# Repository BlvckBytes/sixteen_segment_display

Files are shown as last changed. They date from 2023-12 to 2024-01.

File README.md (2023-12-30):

# sixteen_segment_display

## PCB

### display_group

Four sixteen segment displays are considered to be a group.

### interface

The interface board drives a display group by converting the serial signal into all sixteen segments, including the decimal point, as well as each display's enabled state.

### driver

Has yet to be implemented.

The driver board resembles the bridge between modern devices and the display while also handling the process of detecting the total number of displays, handling the character decoding process, multiplexing displays and playing various animations, like blinking letters or scrolling text.

## Software

### SegmentStates

This project encodes all available segment states in order to display various characters. A decoding table is then generated from this information.

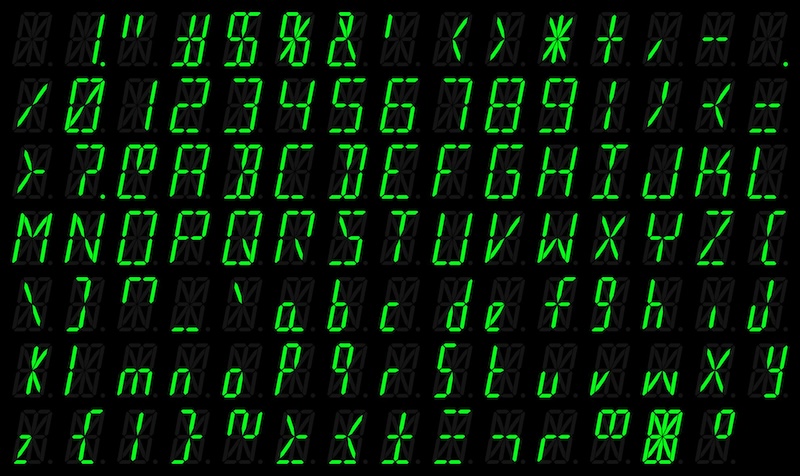
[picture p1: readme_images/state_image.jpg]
states


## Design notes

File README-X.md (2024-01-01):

<!-- This file is rendered by https://github.com/BlvckBytes/readme_helper -->

# sixteen_segment_display

<!-- #toc -->

## Overview

The following drawing represents the dimensions of the displays I've ordered a long time ago on aliexpress.

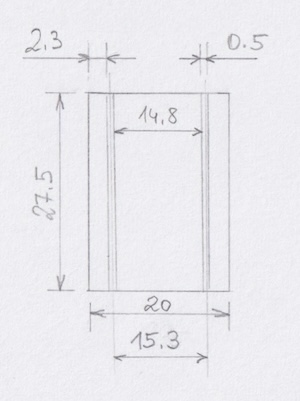
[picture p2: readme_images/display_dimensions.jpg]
Display Dimensions


The following high level diagram provides a quick overview of how groups of four displays each are talked to.

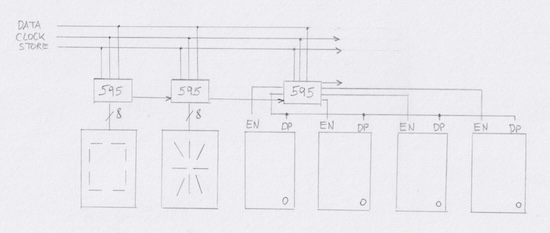
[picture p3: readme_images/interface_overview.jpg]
Interface Overview


## PCB

### display_group

Four sixteen segment displays are considered to be a group.

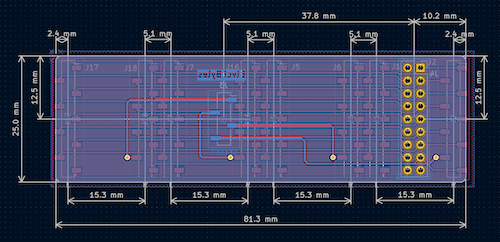
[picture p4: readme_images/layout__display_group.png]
Display Group Layout


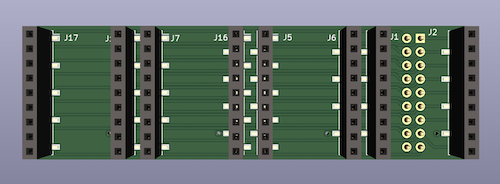
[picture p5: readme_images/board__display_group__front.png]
Display Group Front


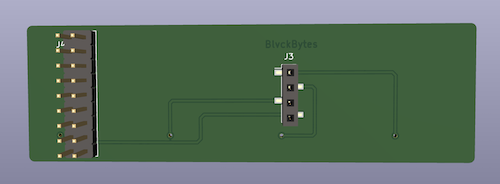
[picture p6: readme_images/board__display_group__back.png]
Display Group Back


### interface

The interface board drives a display group by converting the serial signal into all sixteen segments, including the decimal point, as well as each display's enabled state.

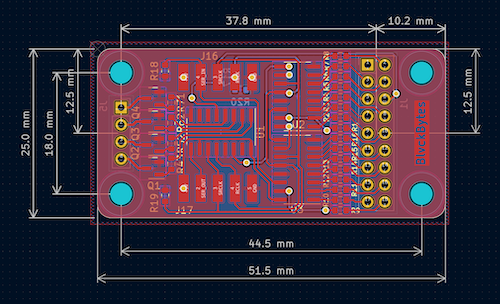
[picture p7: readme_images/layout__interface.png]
Interface Layout


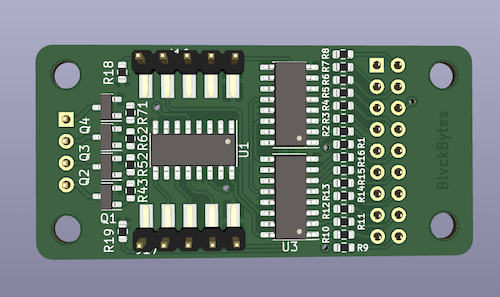
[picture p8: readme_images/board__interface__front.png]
Interface Front


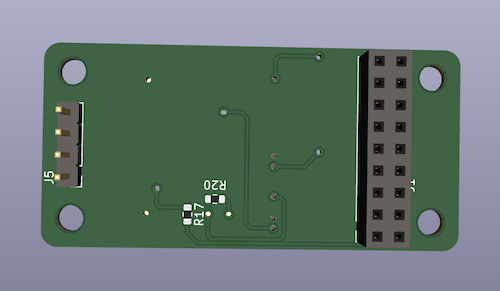
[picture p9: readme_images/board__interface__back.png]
Interface Back


### display_group_and_interface

This board tries to combine both the [Interface](#interface)- as well as the [Display Group Board](#display_group) to save not only on space, but also on the four extra connectors. While it's getting quite crowded, this board should still be manufacturable at home.

There are 35 vias in total, of which 21 are unavoidable (16 segments, 1 decimal point, 4 ground lines, which all have to make it from the front side to the back, where the interface lives), making for 14 "additional" vias. I think that's an acceptable compromise.

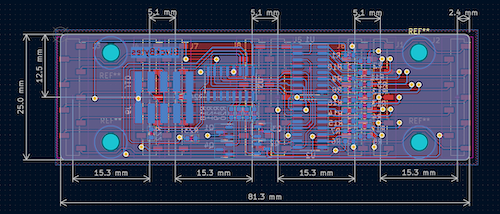
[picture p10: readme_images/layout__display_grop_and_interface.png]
Display Group And Interface Layout


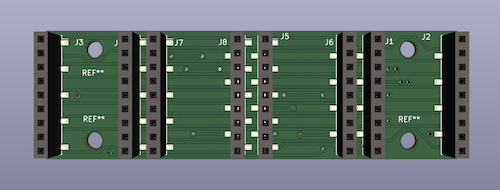
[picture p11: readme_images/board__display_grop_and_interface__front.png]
Display Group And Interface Front


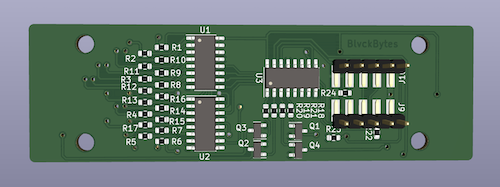
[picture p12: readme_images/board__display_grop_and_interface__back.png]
Display Group And Interface Back


### driver

Has yet to be implemented.

The driver board resembles the bridge between modern devices and the display while also handling the process of detecting the total number of displays, handling the character decoding process, multiplexing displays and playing various animations, like blinking letters or scrolling text.

## Software

### SegmentStates

This project encodes all available segment states in order to display various characters. A decoding table is then generated from this information.

states

### SegmentDriver

Has yet to be implemented.

This project resembles the firmware of the [Driver Board](#driver).

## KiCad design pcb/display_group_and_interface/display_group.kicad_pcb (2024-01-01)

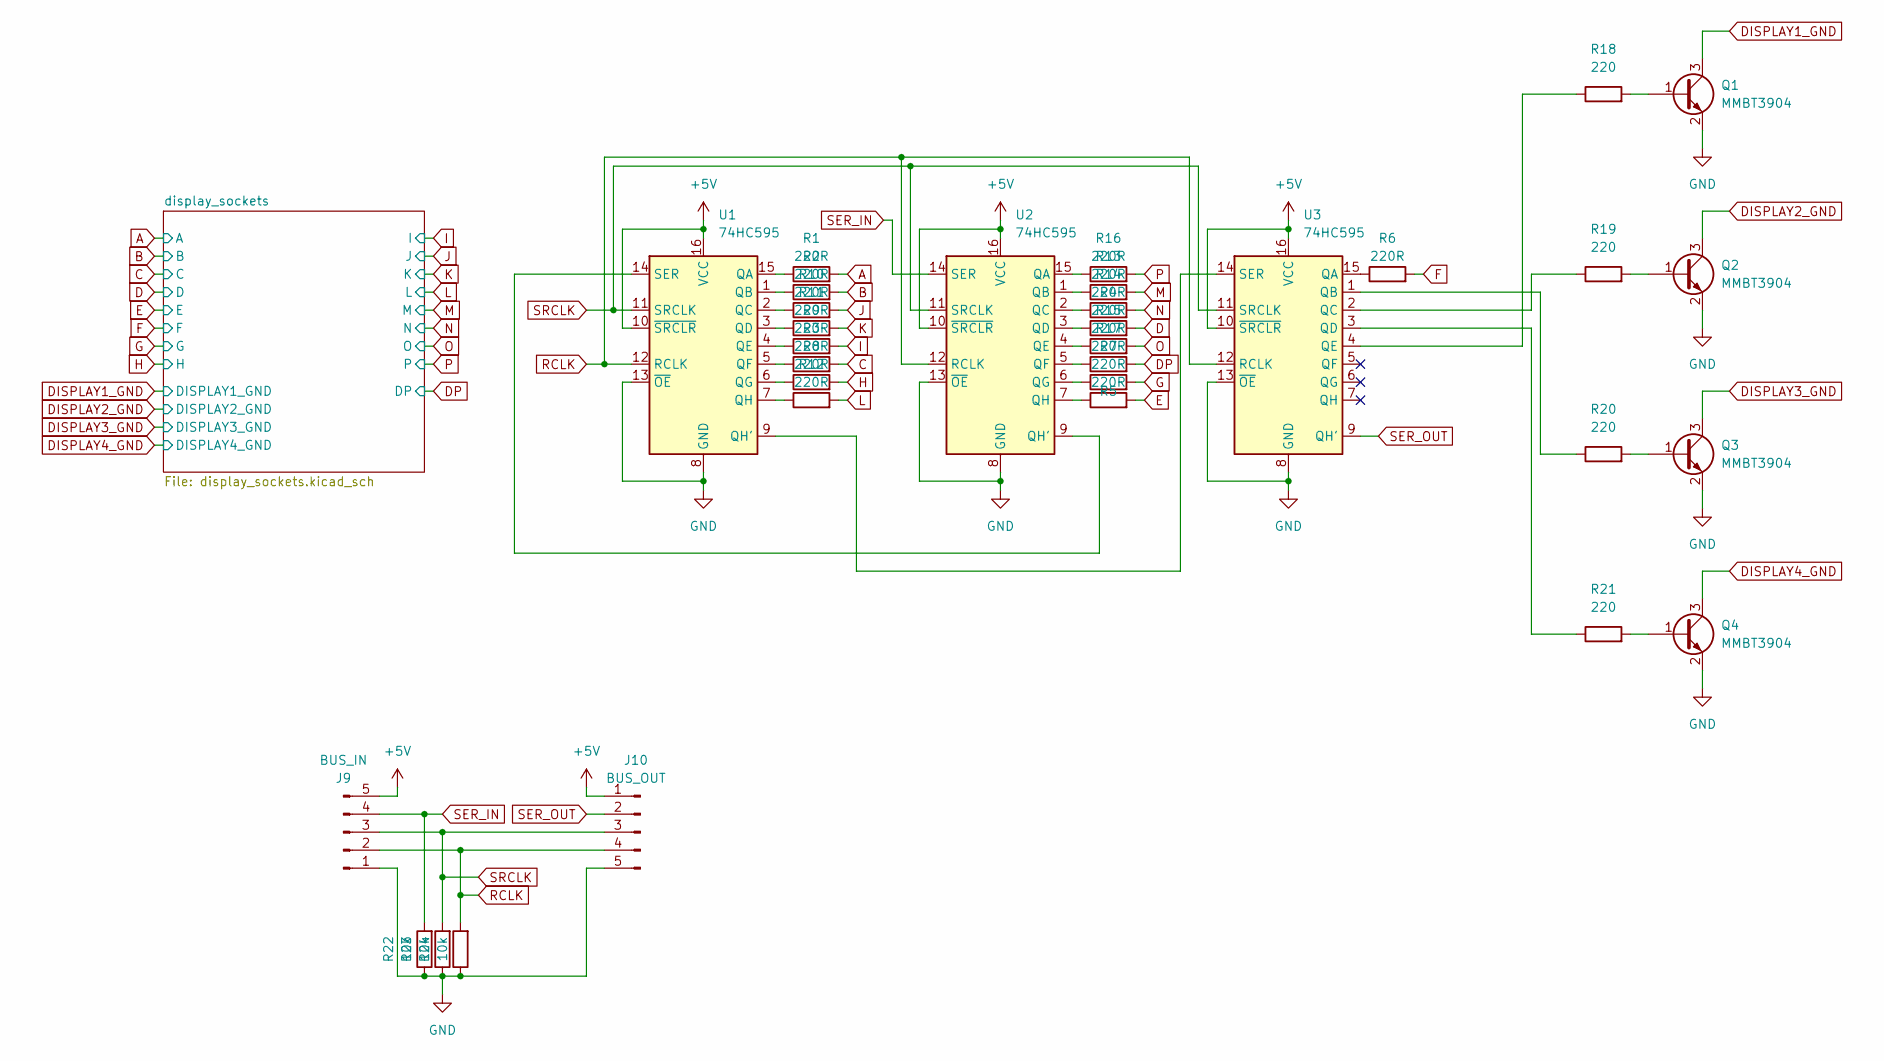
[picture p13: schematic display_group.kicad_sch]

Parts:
J9: BUS_IN; PinHeader_01x05_P2.54mm_Horizontal_SMDified
J10: BUS_OUT; PinHeader_01x05_P2.54mm_Horizontal_SMDified
Q1, Q2, Q3, Q4: MMBT3904; SOT-23
R1, R2, R3, R4, R5, R6, R7, R8, R9, R10, R11, R12, R13, R14, R15, R16, R17: 220R; R_0603_1608Metric
R18, R19, R20, R21: 220; R_0603_1608Metric
R22, R23, R24: 10k; R_0603_1608Metric
U1, U2, U3: 74HC595; SOIC-16_3.9x9.9mm_P1.27mm

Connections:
+5V: J9.5, J10.1, U1.10 (~SRCLR), U1.16 (VCC), U2.10 (~SRCLR), U2.16 (VCC), U3.10 (~SRCLR), U3.16 (VCC)
A: R1.2; also elsewhere on the board
B: R2.2; also elsewhere on the board
C: R3.2; also elsewhere on the board
D: R4.2; also elsewhere on the board
DISPLAY1_GND: Q1.3 (C); also elsewhere on the board
DISPLAY2_GND: Q2.3 (C); also elsewhere on the board
DISPLAY3_GND: Q3.3 (C); also elsewhere on the board
DISPLAY4_GND: Q4.3 (C); also elsewhere on the board
DP: R17.2; also elsewhere on the board
E: R5.2; also elsewhere on the board
F: R6.2; also elsewhere on the board
G: R7.2; also elsewhere on the board
GND: J9.1, J10.5, Q1.2 (E), Q2.2 (E), Q3.2 (E), Q4.2 (E), R22.1, R23.1, R24.1, U1.8 (GND), U1.13 (~OE), U2.8 (GND), U2.13 (~OE), U3.8 (GND), U3.13 (~OE)
H: R8.2; also elsewhere on the board
I: R9.2; also elsewhere on the board
J: R10.2; also elsewhere on the board
K: R11.2; also elsewhere on the board
L: R12.2; also elsewhere on the board
M: R13.2; also elsewhere on the board
N: R14.2; also elsewhere on the board
unnamed: Q1.1 (B), R18.2
unnamed: Q2.1 (B), R19.2
unnamed: Q3.1 (B), R20.2
unnamed: Q4.1 (B), R21.2
unnamed: R1.1, U1.15 (QA)
unnamed: R2.1, U1.1 (QB)
unnamed: R10.1, U1.2 (QC)
unnamed: R11.1, U1.3 (QD)
unnamed: R9.1, U1.4 (QE)
unnamed: R3.1, U1.5 (QF)
unnamed: R8.1, U1.6 (QG)
unnamed: U1.9 (QH'), U3.14 (SER)
unnamed: R12.1, U1.7 (QH)
unnamed: U1.14 (SER), U2.9 (QH')
unnamed: R16.1, U2.15 (QA)
unnamed: R13.1, U2.1 (QB)
unnamed: R14.1, U2.2 (QC)
unnamed: R4.1, U2.3 (QD)
unnamed: R15.1, U2.4 (QE)
unnamed: R17.1, U2.5 (QF)
unnamed: R7.1, U2.6 (QG)
unnamed: R5.1, U2.7 (QH)
unnamed: R6.1, U3.15 (QA)
unnamed: R20.1, U3.1 (QB)
unnamed: R19.1, U3.2 (QC)
unnamed: R21.1, U3.3 (QD)
unnamed: R18.1, U3.4 (QE)
O: R15.2; also elsewhere on the board
P: R16.2; also elsewhere on the board
RCLK: J9.2, J10.4, R24.2, U1.12 (RCLK), U2.12 (RCLK), U3.12 (RCLK)
SER_IN: J9.4, R22.2, U2.14 (SER)
SER_OUT: J10.2, U3.9 (QH')
SRCLK: J9.3, J10.3, R23.2, U1.11 (SRCLK), U2.11 (SRCLK), U3.11 (SRCLK)

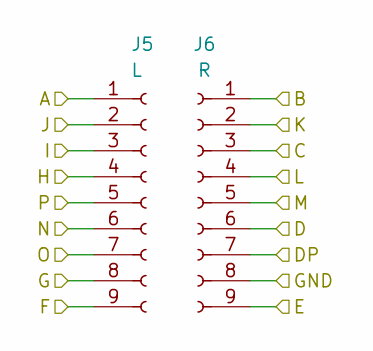
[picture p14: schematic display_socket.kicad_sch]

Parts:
J5: L; PinSocket_1x09_P2.54mm_Vertical_SMD_Pin1Right
J6: R; PinSocket_1x09_P2.54mm_Vertical_SMD_Pin1Right

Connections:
A: J5.1; also elsewhere on the board
B: J6.1; also elsewhere on the board
C: J6.3; also elsewhere on the board
D: J6.6; also elsewhere on the board
DISPLAY3_GND: J6.8; also elsewhere on the board
DP: J6.7; also elsewhere on the board
E: J6.9; also elsewhere on the board
F: J5.9; also elsewhere on the board
G: J5.8; also elsewhere on the board
H: J5.4; also elsewhere on the board
I: J5.3; also elsewhere on the board
J: J5.2; also elsewhere on the board
K: J6.2; also elsewhere on the board
L: J6.4; also elsewhere on the board
M: J6.5; also elsewhere on the board
N: J5.6; also elsewhere on the board
O: J5.7; also elsewhere on the board
P: J5.5; also elsewhere on the board

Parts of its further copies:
J1, J3, J7: L; PinSocket_1x09_P2.54mm_Vertical_SMD_Pin1Right
J2, J4, J8: R; PinSocket_1x09_P2.54mm_Vertical_SMD_Pin1Right

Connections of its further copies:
A: J1.1, J3.1, J7.1; also elsewhere on the board
B: J2.1, J4.1, J8.1; also elsewhere on the board
C: J2.3, J4.3, J8.3; also elsewhere on the board
D: J2.6, J4.6, J8.6; also elsewhere on the board
DISPLAY1_GND: J8.8; also elsewhere on the board
DISPLAY2_GND: J2.8; also elsewhere on the board
DISPLAY4_GND: J4.8; also elsewhere on the board
DP: J2.7, J4.7, J8.7; also elsewhere on the board
E: J2.9, J4.9, J8.9; also elsewhere on the board
F: J1.9, J3.9, J7.9; also elsewhere on the board
G: J1.8, J3.8, J7.8; also elsewhere on the board
H: J1.4, J3.4, J7.4; also elsewhere on the board
I: J1.3, J3.3, J7.3; also elsewhere on the board
J: J1.2, J3.2, J7.2; also elsewhere on the board
K: J2.2, J4.2, J8.2; also elsewhere on the board
L: J2.4, J4.4, J8.4; also elsewhere on the board
M: J2.5, J4.5, J8.5; also elsewhere on the board
N: J1.6, J3.6, J7.6; also elsewhere on the board
O: J1.7, J3.7, J7.7; also elsewhere on the board
P: J1.5, J3.5, J7.5; also elsewhere on the board

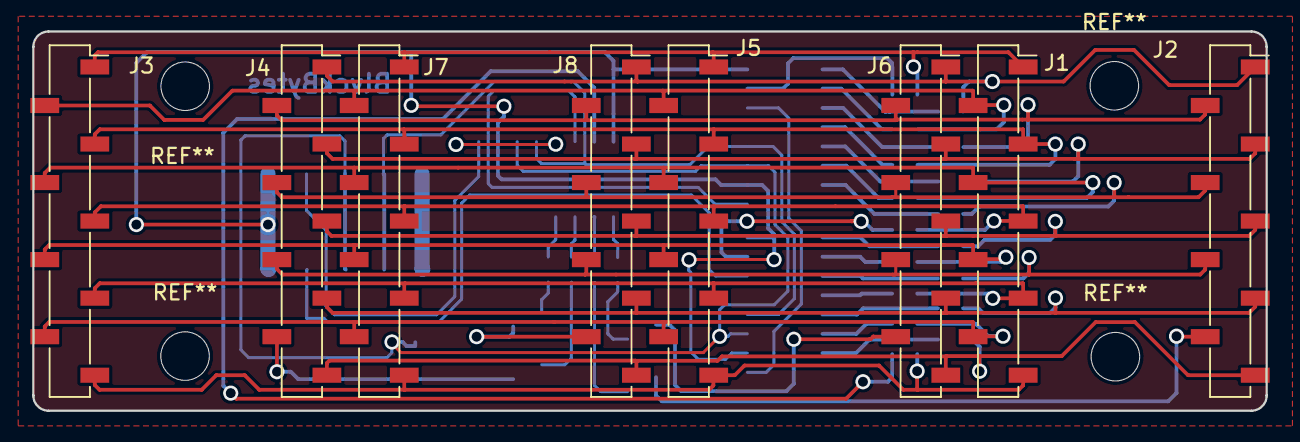
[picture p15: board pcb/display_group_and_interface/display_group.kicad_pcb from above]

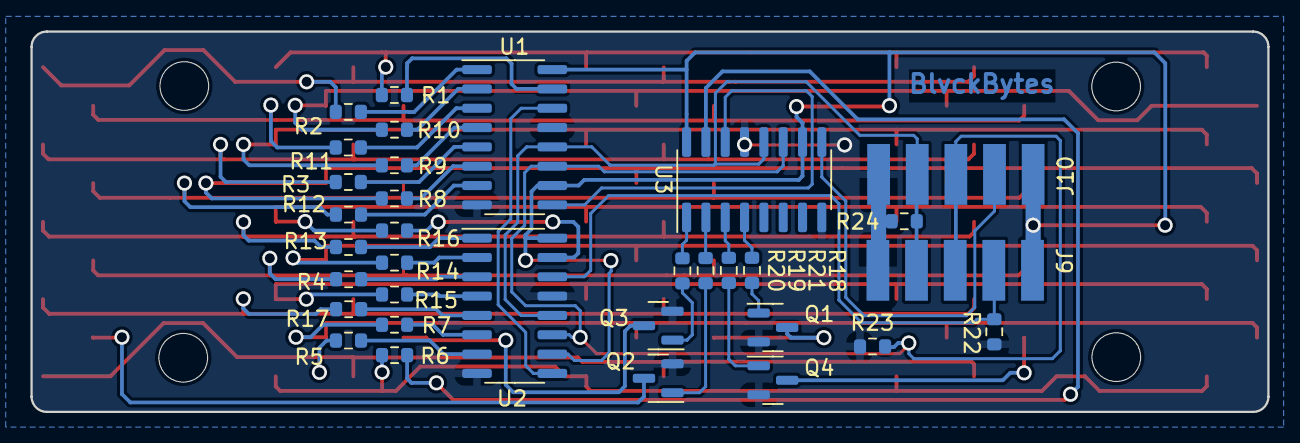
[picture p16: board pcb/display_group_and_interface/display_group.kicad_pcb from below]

Board: 2 copper layers, 81.3 x 25.0 mm, 41 parts (33 on the bottom side), 54 nets.

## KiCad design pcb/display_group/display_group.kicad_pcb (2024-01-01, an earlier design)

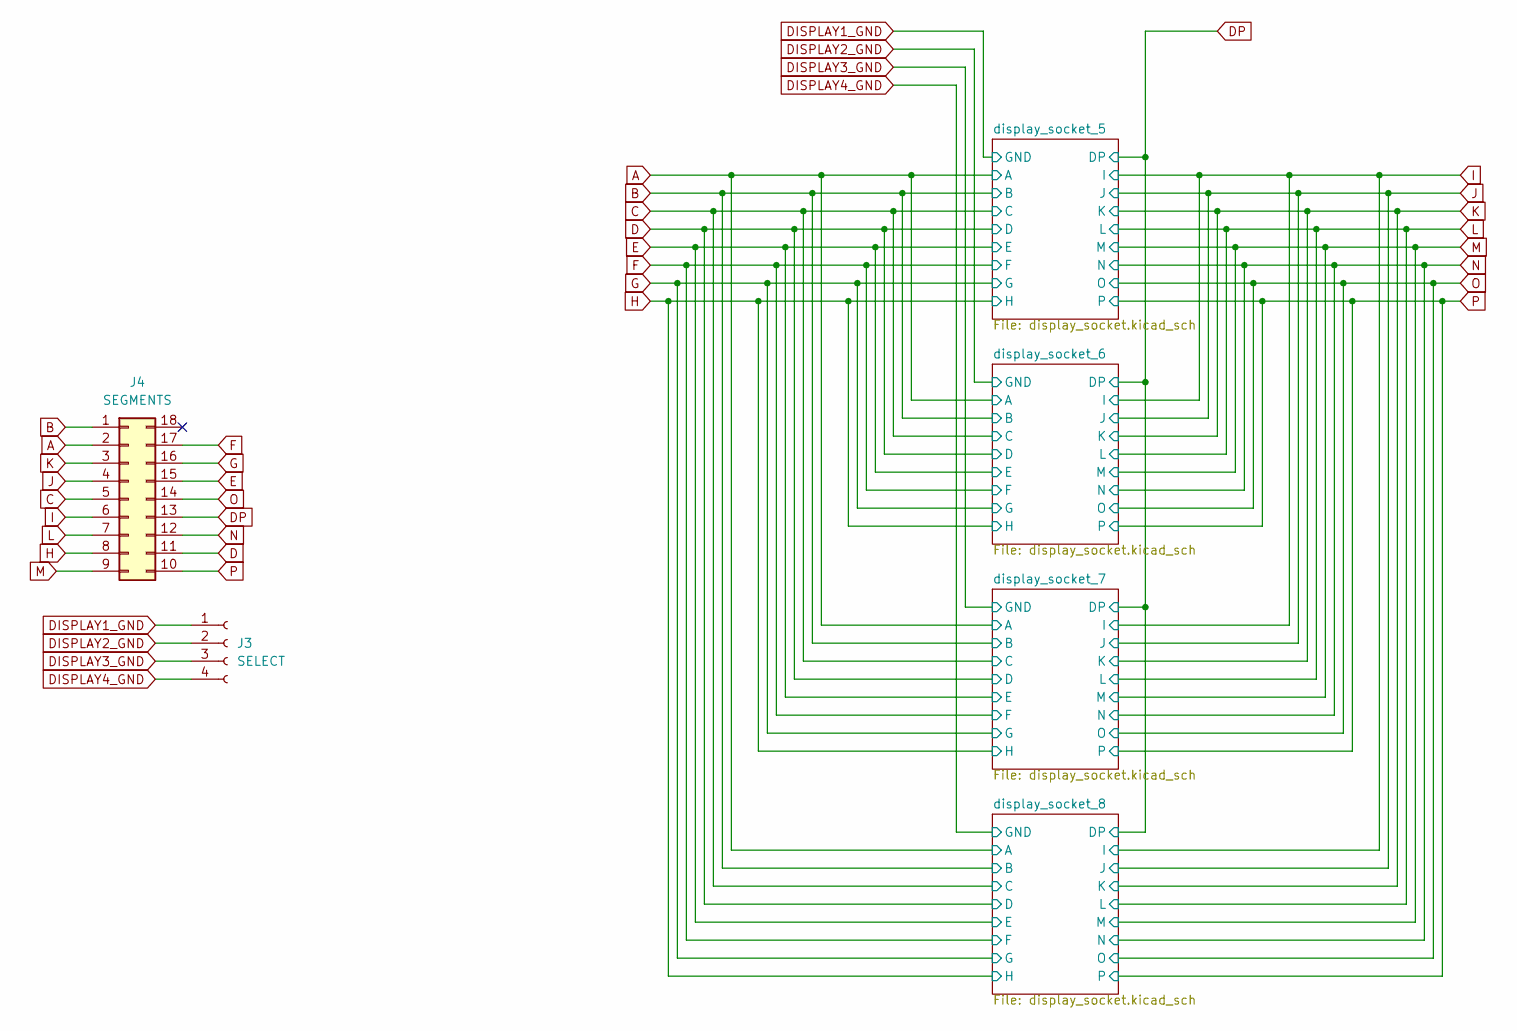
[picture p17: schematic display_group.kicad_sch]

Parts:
J3: SELECT; PinSocket_1x04_P2.54mm_Vertical_SMD_Pin1Left
J4: SEGMENTS; PinHeader_2x09_P2.54mm_Vertical

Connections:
A: J4.2; also elsewhere on the board
B: J4.1; also elsewhere on the board
C: J4.5; also elsewhere on the board
D: J4.11; also elsewhere on the board
DISPLAY1_GND: J3.1; also elsewhere on the board
DISPLAY2_GND: J3.2; also elsewhere on the board
DISPLAY3_GND: J3.3; also elsewhere on the board
DISPLAY4_GND: J3.4; also elsewhere on the board
DP: J4.13; also elsewhere on the board
E: J4.15; also elsewhere on the board
F: J4.17; also elsewhere on the board
G: J4.16; also elsewhere on the board
H: J4.8; also elsewhere on the board
I: J4.6; also elsewhere on the board
J: J4.4; also elsewhere on the board
K: J4.3; also elsewhere on the board
L: J4.7; also elsewhere on the board
M: J4.9; also elsewhere on the board
N: J4.12; also elsewhere on the board
O: J4.14; also elsewhere on the board
P: J4.10; also elsewhere on the board

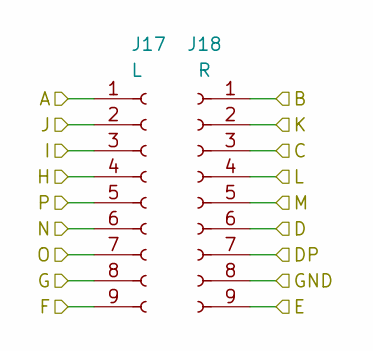
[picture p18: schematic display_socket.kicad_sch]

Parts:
J17: L; PinSocket_1x09_P2.54mm_Vertical_SMD_Pin1Right
J18: R; PinSocket_1x09_P2.54mm_Vertical_SMD_Pin1Right

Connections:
A: J17.1; also elsewhere on the board
B: J18.1; also elsewhere on the board
C: J18.3; also elsewhere on the board
D: J18.6; also elsewhere on the board
DISPLAY1_GND: J18.8; also elsewhere on the board
DP: J18.7; also elsewhere on the board
E: J18.9; also elsewhere on the board
F: J17.9; also elsewhere on the board
G: J17.8; also elsewhere on the board
H: J17.4; also elsewhere on the board
I: J17.3; also elsewhere on the board
J: J17.2; also elsewhere on the board
K: J18.2; also elsewhere on the board
L: J18.4; also elsewhere on the board
M: J18.5; also elsewhere on the board
N: J17.6; also elsewhere on the board
O: J17.7; also elsewhere on the board
P: J17.5; also elsewhere on the board

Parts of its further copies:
J1, J5, J7: L; PinSocket_1x09_P2.54mm_Vertical_SMD_Pin1Right
J2, J6, J16: R; PinSocket_1x09_P2.54mm_Vertical_SMD_Pin1Right

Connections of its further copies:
A: J1.1, J5.1, J7.1; also elsewhere on the board
B: J2.1, J6.1, J16.1; also elsewhere on the board
C: J2.3, J6.3, J16.3; also elsewhere on the board
D: J2.6, J6.6, J16.6; also elsewhere on the board
DISPLAY2_GND: J16.8; also elsewhere on the board
DISPLAY3_GND: J6.8; also elsewhere on the board
DISPLAY4_GND: J2.8; also elsewhere on the board
DP: J2.7, J6.7, J16.7; also elsewhere on the board
E: J2.9, J6.9, J16.9; also elsewhere on the board
F: J1.9, J5.9, J7.9; also elsewhere on the board
G: J1.8, J5.8, J7.8; also elsewhere on the board
H: J1.4, J5.4, J7.4; also elsewhere on the board
I: J1.3, J5.3, J7.3; also elsewhere on the board
J: J1.2, J5.2, J7.2; also elsewhere on the board
K: J2.2, J6.2, J16.2; also elsewhere on the board
L: J2.4, J6.4, J16.4; also elsewhere on the board
M: J2.5, J6.5, J16.5; also elsewhere on the board
N: J1.6, J5.6, J7.6; also elsewhere on the board
O: J1.7, J5.7, J7.7; also elsewhere on the board
P: J1.5, J5.5, J7.5; also elsewhere on the board

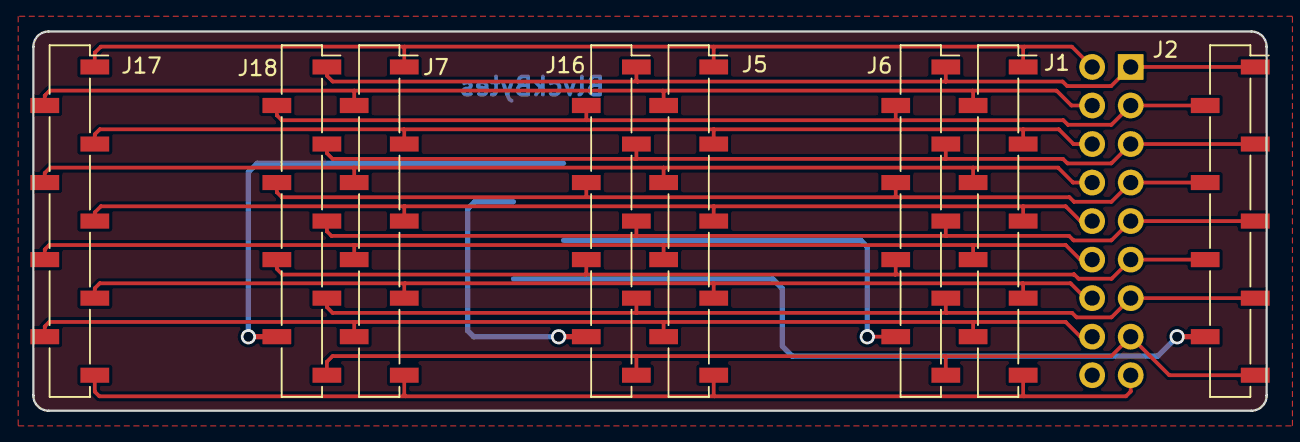
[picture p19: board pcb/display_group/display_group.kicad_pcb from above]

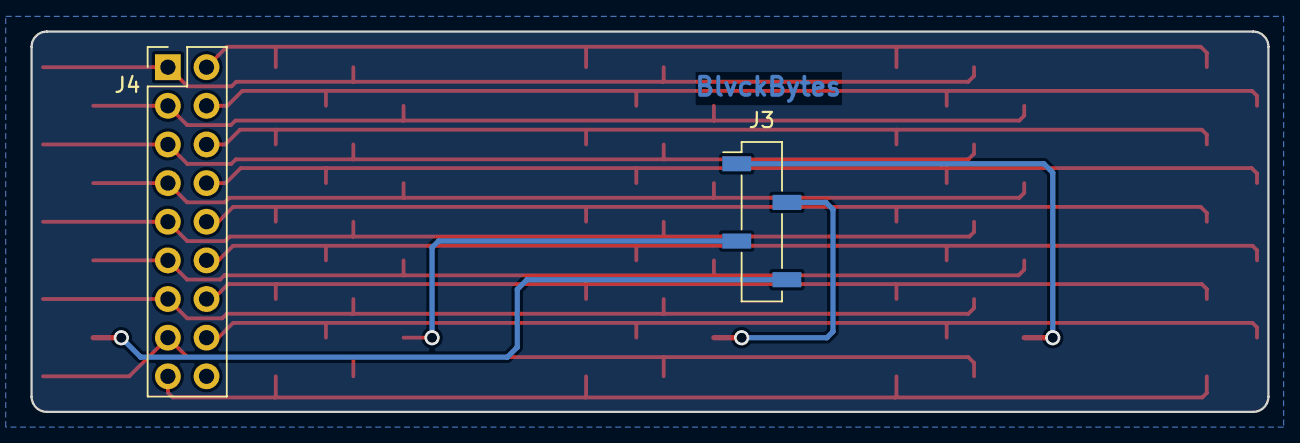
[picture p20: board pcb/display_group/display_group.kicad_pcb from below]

Board: 2 copper layers, 81.3 x 25.0 mm, 10 parts (2 on the bottom side), 21 nets.

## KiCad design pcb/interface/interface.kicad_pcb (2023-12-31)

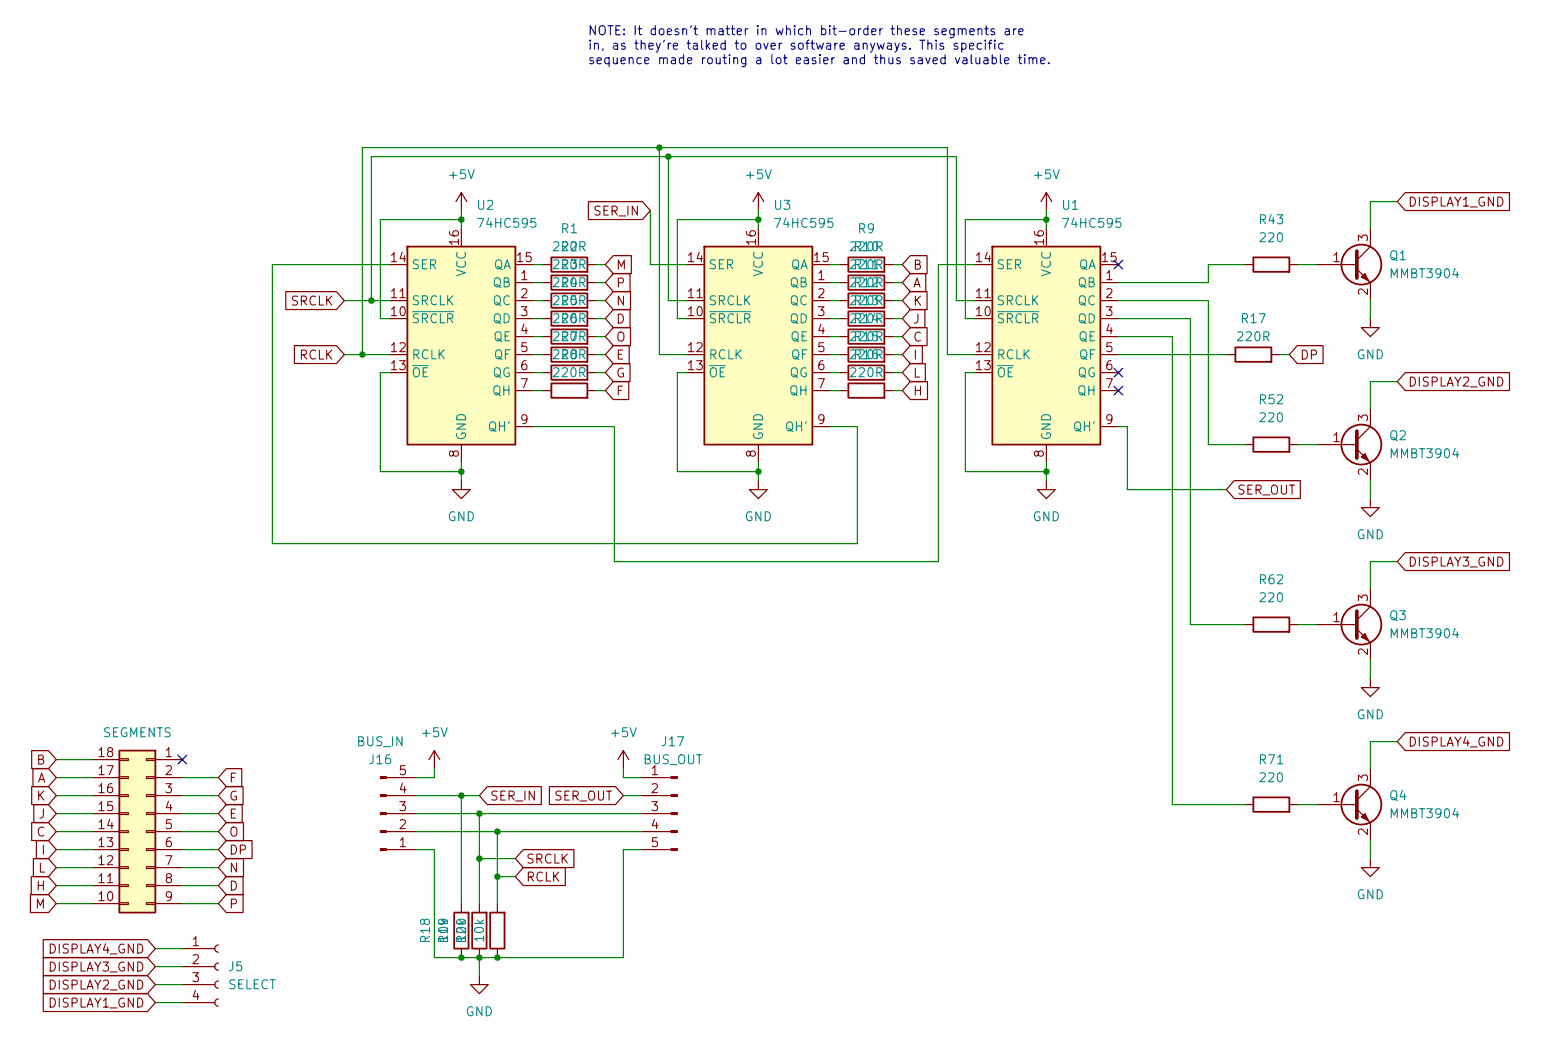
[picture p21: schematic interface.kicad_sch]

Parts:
J1: SEGMENTS; PinSocket_2x09_P2.54mm_Vertical
J5: SELECT; PinHeader_1x04_P2.54mm_Vertical
J16: BUS_IN; PinHeader_01x05_P2.54mm_Horizontal_SMDified
J17: BUS_OUT; PinHeader_01x05_P2.54mm_Horizontal_SMDified
Q1, Q2, Q3, Q4: MMBT3904; SOT-23
R1, R2, R3, R4, R5, R6, R7, R8, R9, R10, R11, R12, R13, R14, R15, R16, R17: 220R; R_0603_1608Metric
R18, R19, R20: 10k; R_0603_1608Metric
R43, R52, R62, R71: 220; R_0603_1608Metric
U1, U2, U3: 74HC595; SOIC-16_3.9x9.9mm_P1.27mm

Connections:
+5V: J16.5, J17.1, U1.10 (~SRCLR), U1.16 (VCC), U2.10 (~SRCLR), U2.16 (VCC), U3.10 (~SRCLR), U3.16 (VCC)
A: J1.17, R10.2
B: J1.18, R9.2
C: J1.14, R13.2
D: J1.8, R4.2
DISPLAY1_GND: J5.4, Q1.3 (C)
DISPLAY2_GND: J5.3, Q2.3 (C)
DISPLAY3_GND: J5.2, Q3.3 (C)
DISPLAY4_GND: J5.1, Q4.3 (C)
DP: J1.6, R17.2
E: J1.4, R6.2
F: J1.2, R8.2
G: J1.3, R7.2
GND: J16.1, J17.5, Q1.2 (E), Q2.2 (E), Q3.2 (E), Q4.2 (E), R18.1, R19.1, R20.1, U1.8 (GND), U1.13 (~OE), U2.8 (GND), U2.13 (~OE), U3.8 (GND), U3.13 (~OE)
H: J1.11, R16.2
I: J1.13, R14.2
J: J1.15, R12.2
K: J1.16, R11.2
L: J1.12, R15.2
M: J1.10, R1.2
N: J1.7, R3.2
unnamed: Q1.1 (B), R43.2
unnamed: Q2.1 (B), R52.2
unnamed: Q3.1 (B), R62.2
unnamed: Q4.1 (B), R71.2
unnamed: R43.1, U1.1 (QB)
unnamed: R52.1, U1.2 (QC)
unnamed: R62.1, U1.3 (QD)
unnamed: R71.1, U1.4 (QE)
unnamed: R17.1, U1.5 (QF)
unnamed: U1.14 (SER), U2.9 (QH')
unnamed: R1.1, U2.15 (QA)
unnamed: R2.1, U2.1 (QB)
unnamed: R3.1, U2.2 (QC)
unnamed: R4.1, U2.3 (QD)
unnamed: R5.1, U2.4 (QE)
unnamed: R6.1, U2.5 (QF)
unnamed: R7.1, U2.6 (QG)
unnamed: R8.1, U2.7 (QH)
unnamed: U2.14 (SER), U3.9 (QH')
unnamed: R9.1, U3.15 (QA)
unnamed: R10.1, U3.1 (QB)
unnamed: R11.1, U3.2 (QC)
unnamed: R12.1, U3.3 (QD)
unnamed: R13.1, U3.4 (QE)
unnamed: R14.1, U3.5 (QF)
unnamed: R15.1, U3.6 (QG)
unnamed: R16.1, U3.7 (QH)
O: J1.5, R5.2
P: J1.9, R2.2
RCLK: J16.2, J17.4, R20.2, U1.12 (RCLK), U2.12 (RCLK), U3.12 (RCLK)
SER_IN: J16.4, R18.2, U3.14 (SER)
SER_OUT: J17.2, U1.9 (QH')
SRCLK: J16.3, J17.3, R19.2, U1.11 (SRCLK), U2.11 (SRCLK), U3.11 (SRCLK)

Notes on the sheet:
NOTE: It doesn't matter in which bit-order these segments are in, as they're talked to over software anyways. This specific sequence made routing a lot easier and thus saved valuable time.

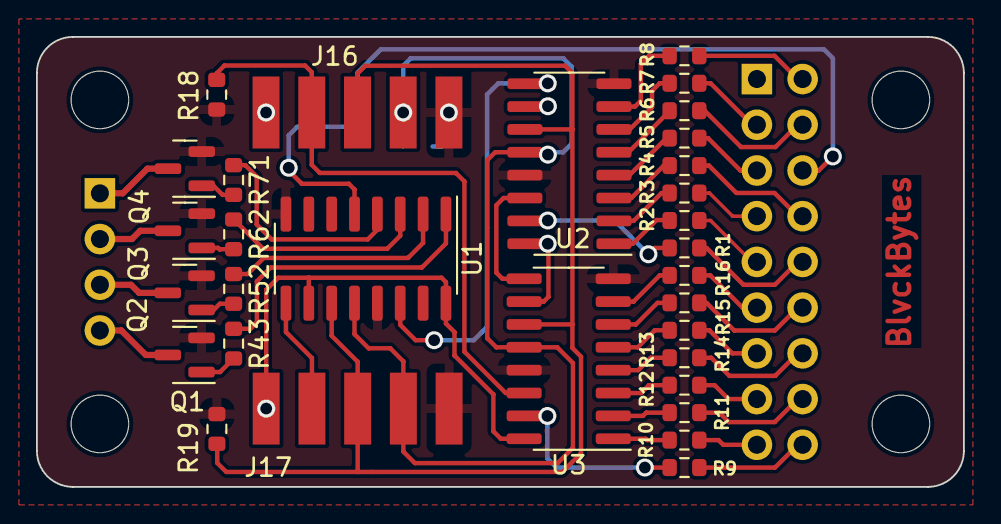
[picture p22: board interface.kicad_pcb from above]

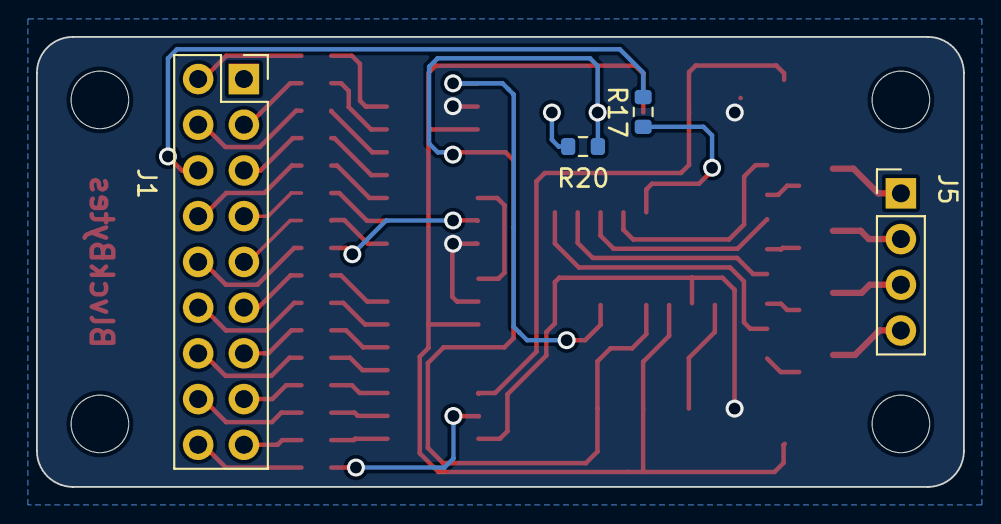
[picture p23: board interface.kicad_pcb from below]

Board: 2 copper layers, 51.5 x 25.0 mm, 35 parts (4 on the bottom side), 54 nets.

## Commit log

2023-12-30 cleaned up, reworked and (so far) finalized the interface board
    [interface.kicad_pcb, interface.kicad_sch]
2023-12-30 added missing resistors to the interface board
    [interface.kicad_pcb, interface.kicad_sch]
2023-12-30 cleaned up, reworked and (so far) finalized the display-group board
    [display_group.kicad_pcb, display_group.kicad_sch, display_socket.kicad_sch]
2023-12-30 increased ground trace width from .25 to .35
    [display_group.kicad_pcb, interface.kicad_pcb]
2023-12-31 added missing input pulldown resistors to the interface board
    [interface.kicad_pcb, interface.kicad_sch]
2024-01-01 added name embossing to the display_group board
    [display_group.kicad_pcb]
2024-01-01 added the display_group_and_interface board
    [display_group.kicad_pcb, display_group.kicad_sch, display_socket.kicad_sch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]
